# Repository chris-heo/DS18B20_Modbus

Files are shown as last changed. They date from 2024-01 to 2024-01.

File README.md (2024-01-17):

# Modbus adapter for DS18B20 temperature sensors (and more)

Quick facts:
* 7 channels for DS18B20 (and compatible devices)
* 1 ADC channel
* 8 pulse counters
* I2C interface for AMS AS5600 magnetic encoder
* Modbus RTU
* ATtiny1616

[Documentation](https://hobbyelektronik.org/w/index.php/DS18B20-Modbus-Adapter) (German)

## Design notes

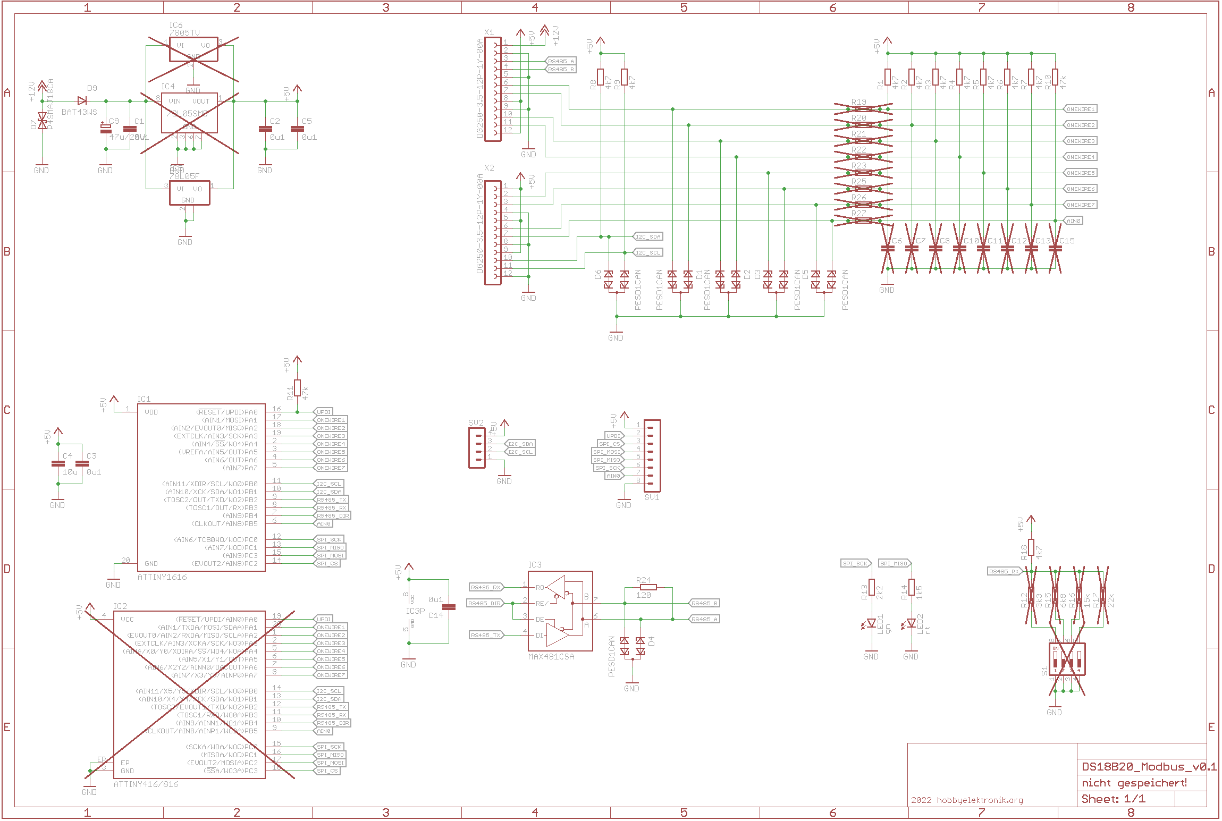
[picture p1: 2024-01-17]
hardware/DS18B20Modbus_v0.1_sch.png

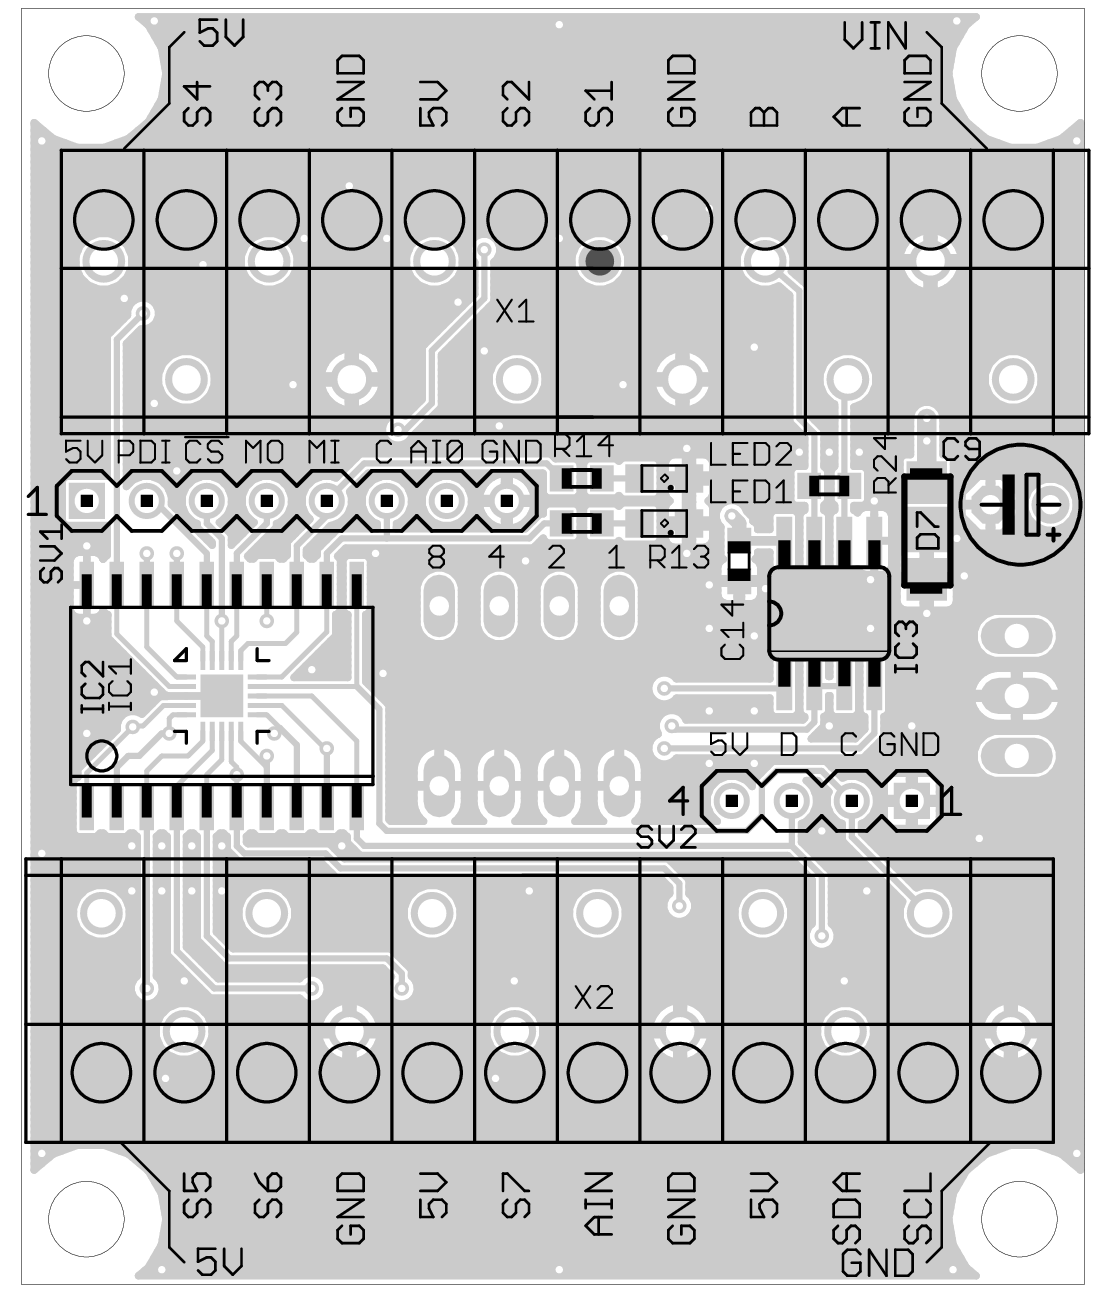
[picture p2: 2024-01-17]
hardware/DS18B20Modbus_v0.1_pcb_top_assy.png

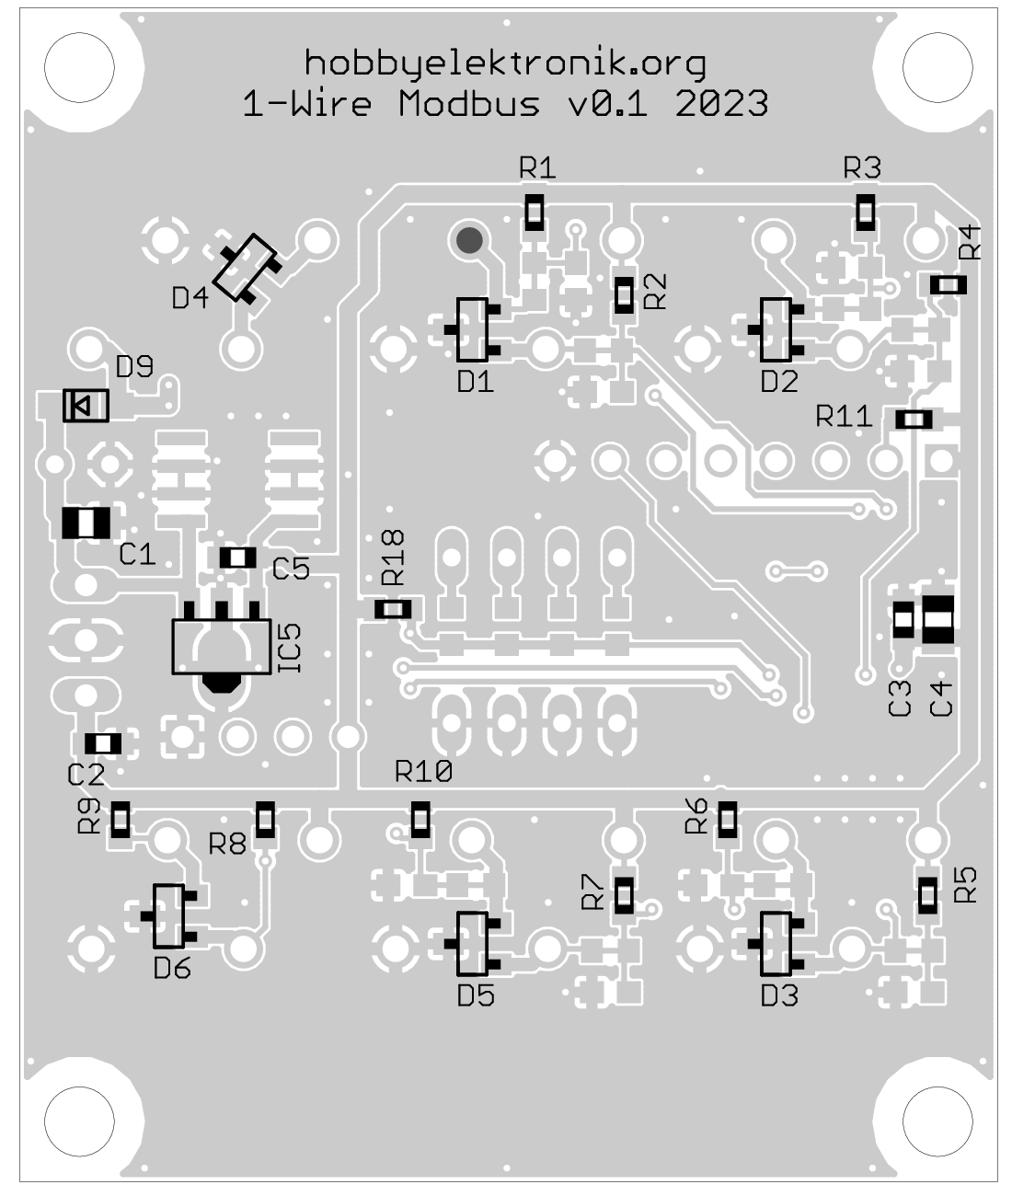
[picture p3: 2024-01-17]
hardware/DS18B20Modbus_v0.1_pcb_bot_assy.png

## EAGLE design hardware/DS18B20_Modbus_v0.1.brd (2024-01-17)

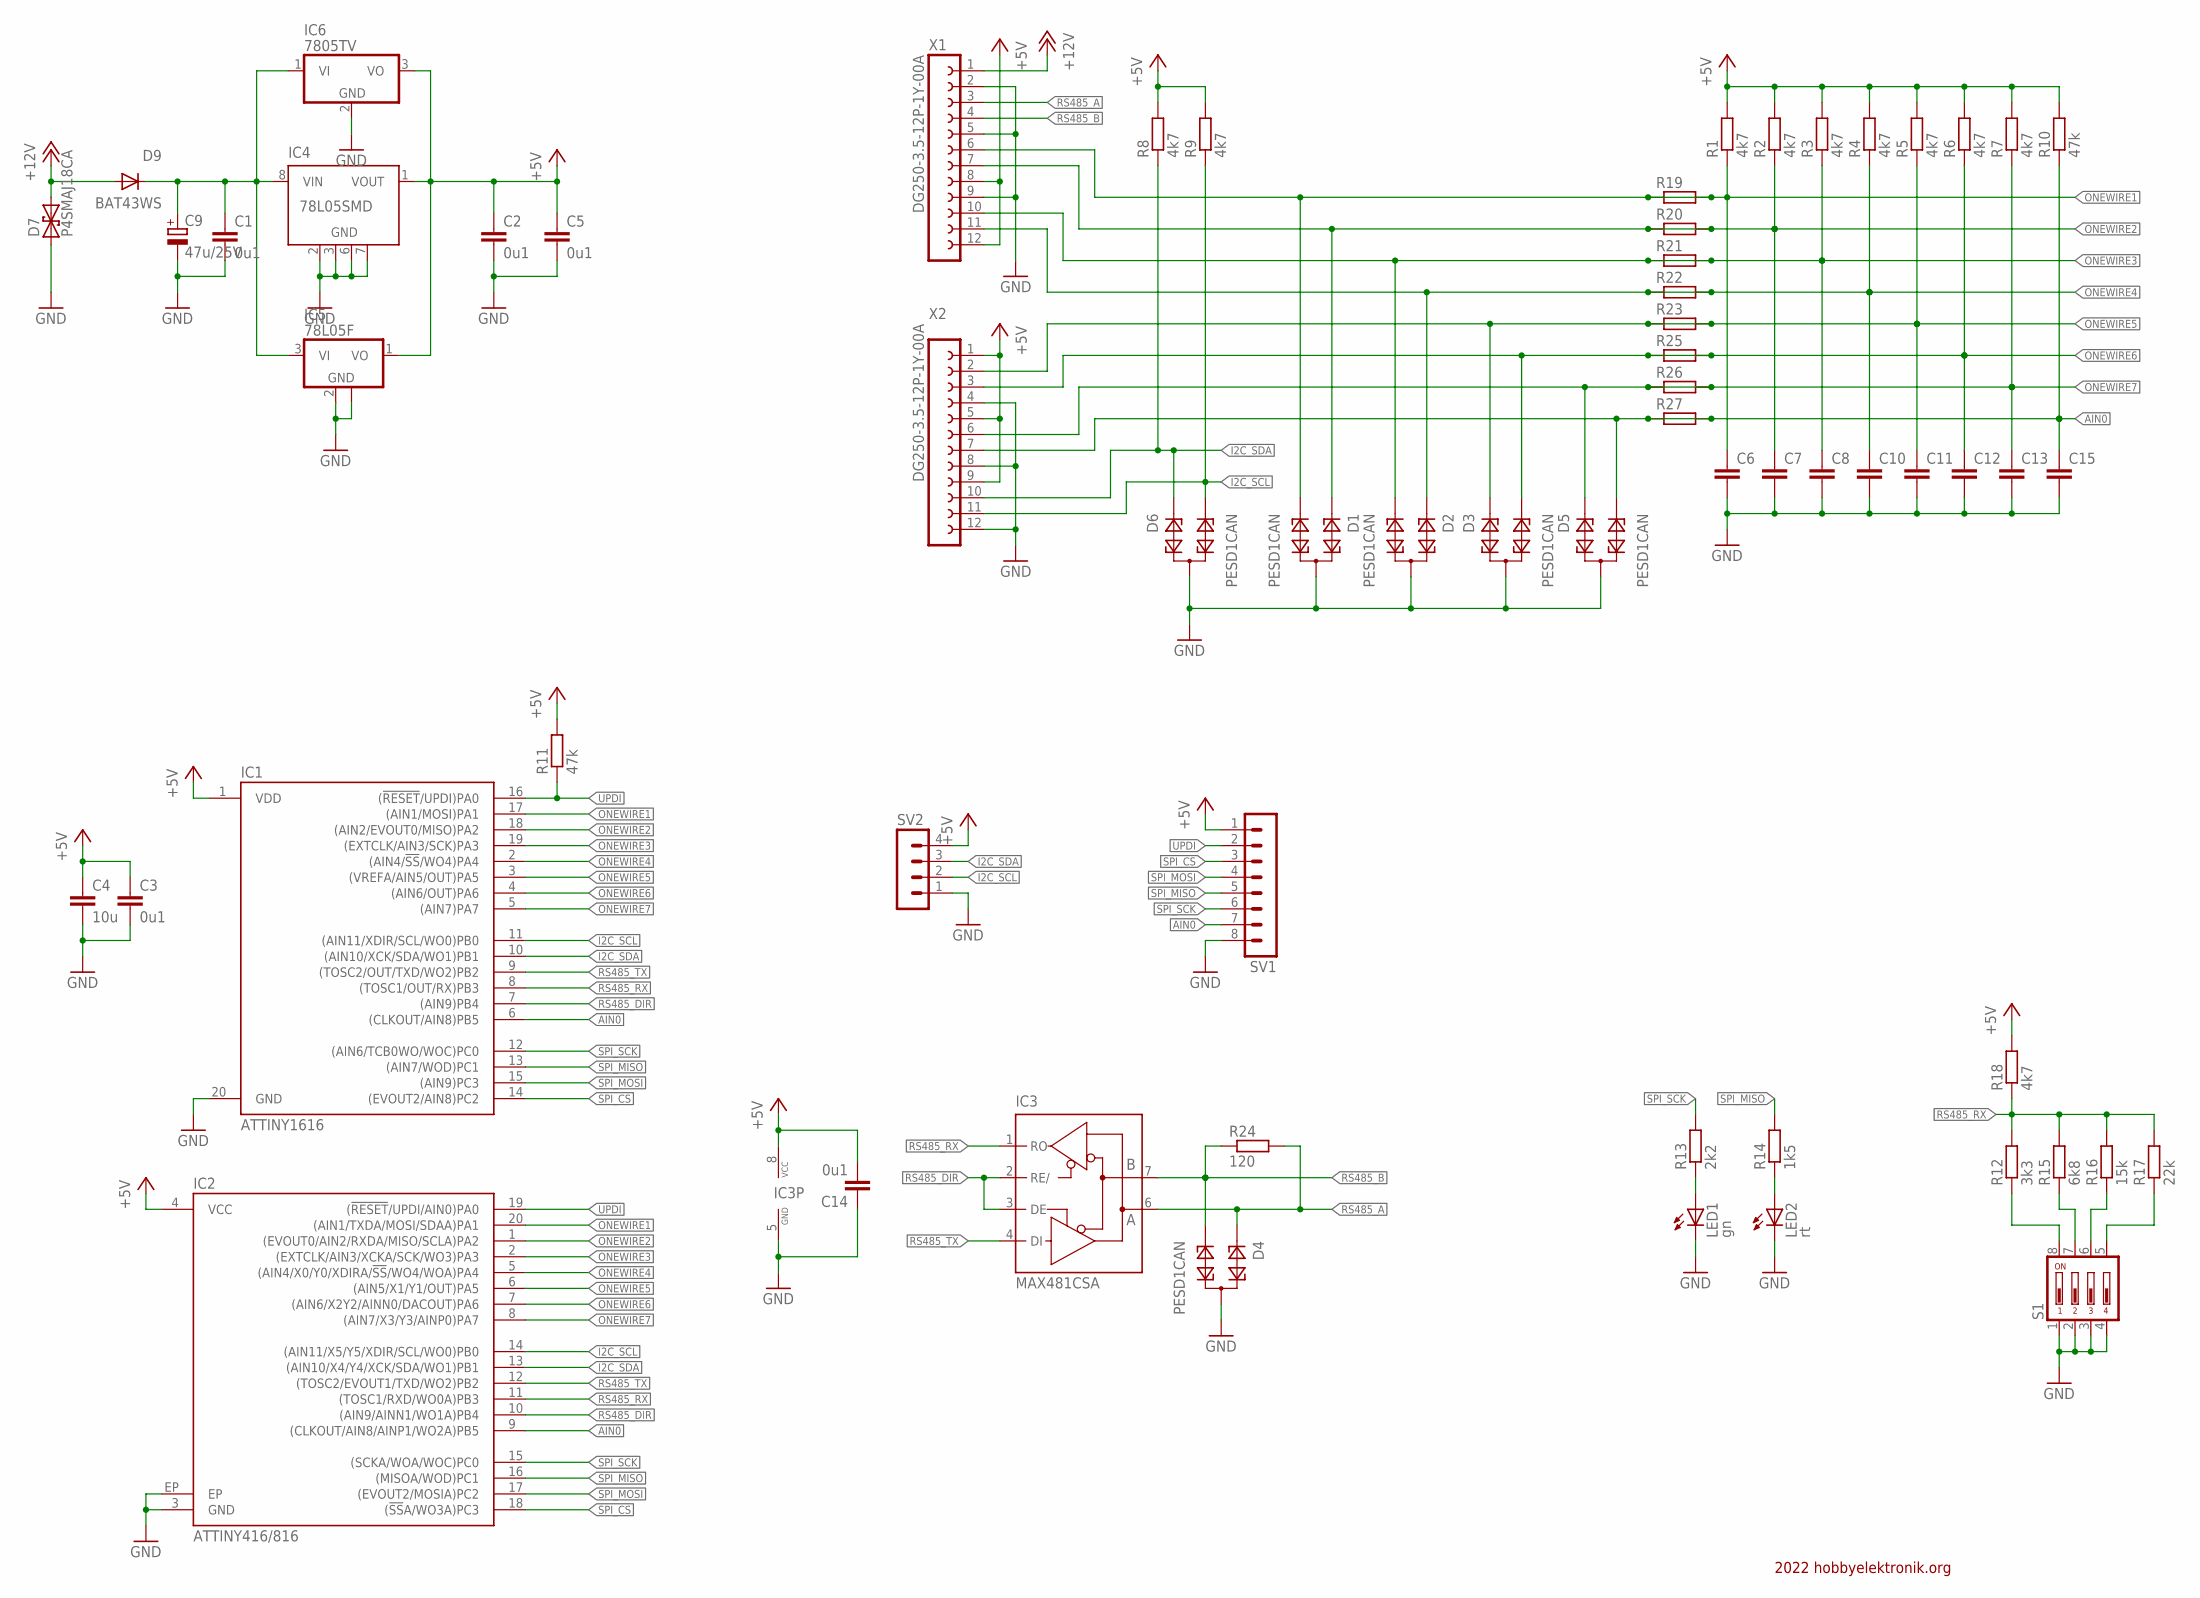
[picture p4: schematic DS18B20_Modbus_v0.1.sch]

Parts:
C1: 0u1; C0805
C2, C3, C5, C14: 0u1; C0603
C4: 10u; C0805
C6, C7, C8, C10, C11, C12, C13, C15: C-EUC0603; C0603
C9: 47u/25V; E2,5-5
D1, D2, D3, D4, D5, D6: PESD1CAN; SOT23
D7: P4SMAJ18CA; DO214AC
D9: BAT43WS; SOD323-W
IC1: ATTINY1616; SO20_T1616
IC2: ATTINY416/816; ZCL_VQFN-20
IC3: MAX481CSA; SO08
IC4: 78L05SMD; SO08
IC5: 78L05F; SOT89
IC6: 7805TV; TO220V
LED1: gn; SML0805
LED2: rt; SML0805
R1, R2, R3, R4, R5, R6, R7, R8, R9, R18: 4k7; R0603
R10, R11: 47k; R0603
R12: 3k3; R0603
R13: 2k2; R0603
R14: 1k5; R0603
R15: 6k8; R0603
R16: 15k; R0603
R17: 22k; R0603
R19, R20, R21, R22, R23, R25, R26, R27: R-EU_R0603; R0603
R24: 120; R0603
S1: DS04; DS-04
SV1: MA08-1R
SV2: MA04-1R
X1, X2: DG250-3.5-12P-1Y-00A

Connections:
+5V: C2.1, C3.1, C4.1, C5.1, C14.2, IC1.1 (VDD), IC2.4 (VCC), IC3.8 (VCC), IC4.1 (VOUT), IC5.1 (VO), IC6.3 (VO), R1.2, R2.2, R3.2, R4.2, R5.2, R6.2, R7.2, R8.2, R9.2, R10.2, R11.2, R18.2, SV1.1, SV2.4, X1.8, X1.12, X2.1, X2.5, X2.9
+12V: D7.2, D9.A, X1.1
AIN0: C15.1, D5.2, IC1.6 ((CLKOUT/AIN8)PB5), IC2.9 ((CLKOUT/AIN8/AINP1/WO2A)PB5), R10.1, R27.1, R27.2, SV1.7, X2.7
GND: C1.2, C2.2, C3.2, C4.2, C5.2, C6.2, C7.2, C8.2, C9.-, C10.2, C11.2, C12.2, C13.2, C14.1, C15.2, D1.3, D2.3, D3.3, D4.3, D5.3, D6.3, D7.1, IC1.20 (GND), IC2.3 (GND), IC2.EP, IC3.5 (GND), IC4.2 (GND), IC4.3 (GND), IC4.6 (GND), IC4.7 (GND), IC5.2 (GND), IC5.2@1 (GND), IC6.2 (GND), LED1.C, LED2.C, S1.1, S1.2, S1.3, S1.4, SV1.8, SV2.1, X1.2, X1.5, X1.9, X2.4, X2.8, X2.12
I2C_SCL: D6.2, IC1.11 ((AIN11/XDIR/SCL/WO0)PB0), IC2.14 ((AIN11/X5/Y5/XDIR/SCL/WO0)PB0), R9.1, SV2.2, X2.11
I2C_SDA: D6.1, IC1.10 ((AIN10/XCK/SDA/WO1)PB1), IC2.13 ((AIN10/X4/Y4/XCK/SDA/WO1)PB1), R8.1, SV2.3, X2.10
unnamed: R12.1, S1.8
unnamed: R15.1, S1.7
unnamed: R16.1, S1.6
unnamed: R17.1, S1.5
unnamed: LED1.A, R13.1
unnamed: LED2.A, R14.1
unnamed: C1.1, C9.+, D9.C, IC4.8 (VIN), IC5.3 (VI), IC6.1 (VI)
ONEWIRE1: C6.1, D1.2, IC1.17 ((AIN1/MOSI)PA1), IC2.20 ((AIN1/TXDA/MOSI/SDAA)PA1), R1.1, R19.1, R19.2, X1.6
ONEWIRE2: C7.1, D1.1, IC1.18 ((AIN2/EVOUT0/MISO)PA2), IC2.1 ((EVOUT0/AIN2/RXDA/MISO/SCLA)PA2), R2.1, R20.1, R20.2, X1.7
ONEWIRE3: C8.1, D2.2, IC1.19 ((EXTCLK/AIN3/SCK)PA3), IC2.2 ((EXTCLK/AIN3/XCKA/SCK/WO3)PA3), R3.1, R21.1, R21.2, X1.10
ONEWIRE4: C10.1, D2.1, IC1.2 ((AIN4/!SS!/WO4)PA4), IC2.5 ((AIN4/X0/Y0/XDIRA/!SS!/WO4/WOA)PA4), R4.1, R22.1, R22.2, X1.11
ONEWIRE5: C11.1, D3.1, IC1.3 ((VREFA/AIN5/OUT)PA5), IC2.6 ((AIN5/X1/Y1/OUT)PA5), R5.1, R23.1, R23.2, X2.2
ONEWIRE6: C12.1, D3.2, IC1.4 ((AIN6/OUT)PA6), IC2.7 ((AIN6/X2Y2/AINN0/DACOUT)PA6), R6.1, R25.1, R25.2, X2.3
ONEWIRE7: C13.1, D5.1, IC1.5 ((AIN7)PA7), IC2.8 ((AIN7/X3/Y3/AINP0)PA7), R7.1, R26.1, R26.2, X2.6
RS485_A: D4.1, IC3.6 (A), R24.2, X1.3
RS485_B: D4.2, IC3.7 (B), R24.1, X1.4
RS485_DIR: IC1.7 ((AIN9)PB4), IC2.10 ((AIN9/AINN1/WO1A)PB4), IC3.2 (RE/), IC3.3 (DE)
RS485_RX: IC1.8 ((TOSC1/OUT/RX)PB3), IC2.11 ((TOSC1/RXD/WO0A)PB3), IC3.1 (RO), R12.2, R15.2, R16.2, R17.2, R18.1
RS485_TX: IC1.9 ((TOSC2/OUT/TXD/WO2)PB2), IC2.12 ((TOSC2/EVOUT1/TXD/WO2)PB2), IC3.4 (DI)
SPI_CS: IC1.14 ((EVOUT2/AIN8)PC2), IC2.18 ((!SS!A/WO3A)PC3), SV1.3
SPI_MISO: IC1.13 ((AIN7/WOD)PC1), IC2.16 ((MISOA/WOD)PC1), R14.2, SV1.5
SPI_MOSI: IC1.15 ((AIN9)PC3), IC2.17 ((EVOUT2/MOSIA)PC2), SV1.4
SPI_SCK: IC1.12 ((AIN6/TCB0WO/WOC)PC0), IC2.15 ((SCKA/WOA/WOC)PC0), R13.2, SV1.6
UPDI: IC1.16 ((!RESET!/UPDI)PA0), IC2.19 ((!RESET!/UPDI/AIN0)PA0), R11.1, SV1.2

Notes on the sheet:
2022 hobbyelektronik.org

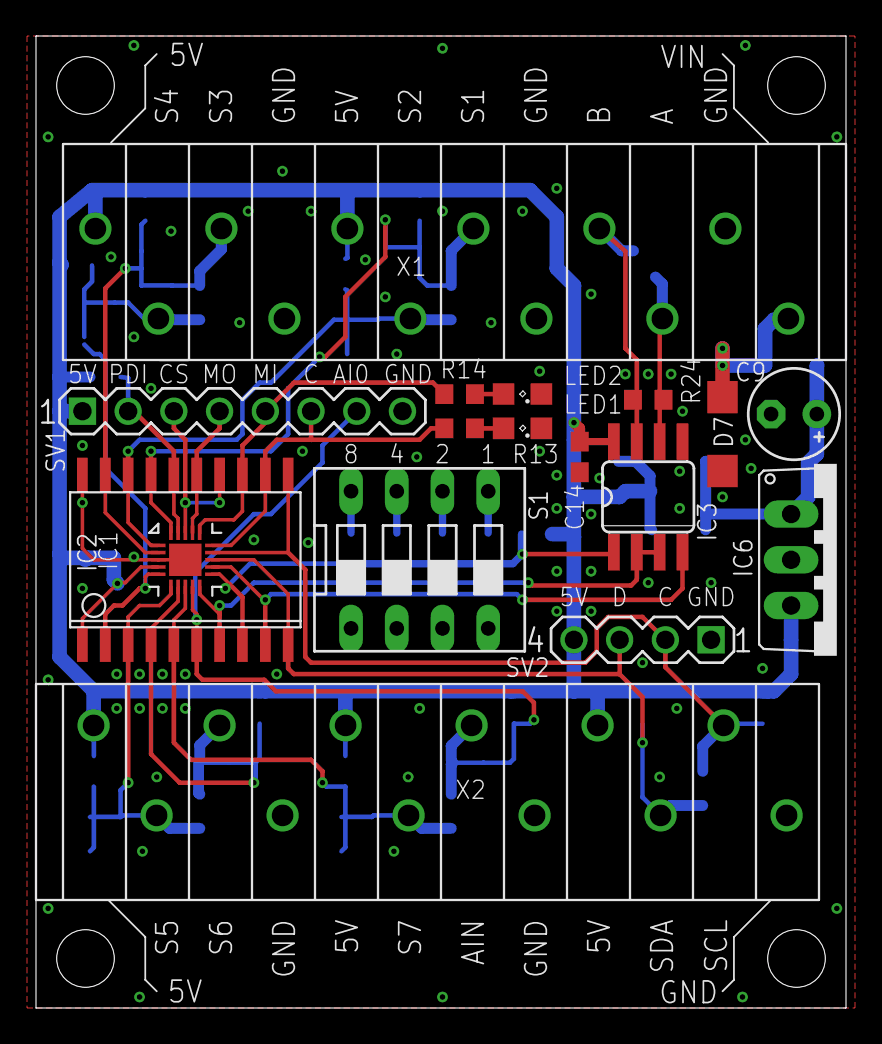
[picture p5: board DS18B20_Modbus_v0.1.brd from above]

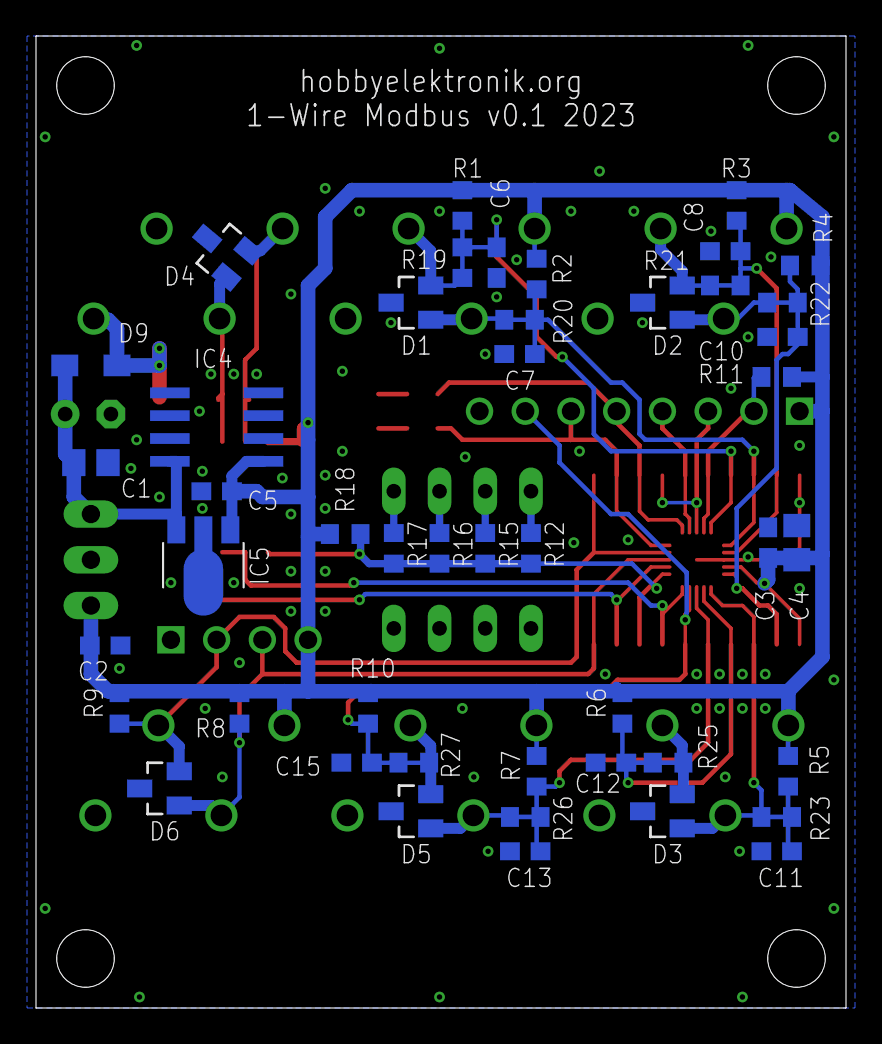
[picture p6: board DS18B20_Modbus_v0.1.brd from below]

Board: 2 copper layers, 45.0 x 54.0 mm, 63 parts (46 on the bottom side), 30 nets.

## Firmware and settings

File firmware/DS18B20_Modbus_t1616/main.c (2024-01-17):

#include <avr/io.h>
#include "onewire.h"
#include <avr/interrupt.h>
#include <util/delay.h>
#include <stdbool.h>
#include "yaMBSiavr.h"
#include "ds18b20.h"
#include "i2cm.h"
#include "as5600.h"
#include <avr/pgmspace.h>
#include "config.h"
#include <avr/wdt.h>

FUSE_t __fuse __attribute__((section (".fuse"))) =
{
    .WDTCFG = WINDOW_OFF_gc | PERIOD_16CLK_gc,
    .BODCFG = BOD_LVL_BODLEVEL2_gc | BOD_SAMPFREQ_1KHZ_gc | BOD_ACTIVE_ENABLED_gc | BOD_SLEEP_DIS_gc,
    .OSCCFG = (0 << FUSE_OSCLOCK_bp) | FREQSEL_16MHZ_gc,
    .TCD0CFG = (0 << FUSE_CMPDEN_bp) | (0 << FUSE_CMPCEN_bp) | (0 << FUSE_CMPBEN_bp) | (0 << FUSE_CMPAEN_bp) | (0 << FUSE_CMPD_bp) | (0 << FUSE_CMPC_bp) | (0 << FUSE_CMPB_bp) | (0 << FUSE_CMPA_bp),
    .SYSCFG0 = CRCSRC_NOCRC_gc | RSTPINCFG_UPDI_gc | (1 << FUSE_EESAVE_bp),
    .SYSCFG1 = CLKCTRL_CSUT_64K_gc,
    .APPEND = 0x00,
    .BOOTEND = 0x00,
};

volatile uint8_t sys_ticks = 0;

#define led_red_on() PORTC.OUTSET = PIN1_bm
#define led_red_off() PORTC.OUTCLR = PIN1_bm

#define led_green_on() PORTC.OUTSET = PIN0_bm
#define led_green_off() PORTC.OUTCLR = PIN0_bm

uint8_t modbus_act_cnt = 0;

const __flash uint8_t adc_scanchannels[] =
{
    ADC_SCANCHANNELS
};

//////////////////////////////////////////////////////////////////////////
// helper functions

#define array_length(arr) (sizeof(arr) / sizeof(typeof(*arr)))

inline bool postscaler8(uint8_t ticks_passed, uint8_t* postscaler, uint8_t scaling)
{
    *postscaler += ticks_passed;
    if(*postscaler >= scaling)
    {
        *postscaler -= scaling;
        return true;
    }
    return false;
}

inline bool postscaler16(uint8_t ticks_passed, uint16_t* postscaler, uint16_t scaling)
{
    *postscaler += ticks_passed;
    if(*postscaler >= scaling)
    {
        *postscaler -= scaling;
        return true;
    }
    return false;
}

//////////////////////////////////////////////////////////////////////////
// system ticks

void systick_init(void)
{
    TCB0.CTRLA = TCB_CLKSEL_CLKDIV1_gc | (1 << TCB_ENABLE_bp);
    //TCB0.CTRLB = TCB_CNTMODE_0_bm;
    TCB0.INTCTRL = 1 << TCB_CAPT_bp;
    TCB0.CCMP = 1600; // 100µs @ 16 MHz
}

ISR(TCB0_INT_vect)
{
    TCB0.INTFLAGS = 1 << TCB_CAPT_bp;
    modbusTickTimer();
    sys_ticks++;
}

//////////////////////////////////////////////////////////////////////////
// modbus stuff

volatile uint8_t instate = 0;
volatile uint8_t outstate = 0;
volatile uint16_t inputRegisters[MODBUS_REGS_INPUT_CNT];
volatile uint16_t holdingRegisters[MODBUS_REGS_HOLDING_CNT];

void modbusGet(void)
{

    if (modbusGetBusState() & (1<<ReceiveCompleted))
    {
        modbus_act_cnt = MODBUS_ACT_DURATION;
        led_green_off();
        
        switch(rxbuffer[1]) 
        {
            case fcReadCoilStatus: //read single/multiple coils
            {
                modbusExchangeBits(&outstate, 0, 8);
            }
            break;
            
            case fcReadInputStatus: //read single/multiple inputs
            {
                volatile uint8_t inps = 0; //ReadIns();
                modbusExchangeBits(&inps, 0, 8);
            }
            break;
            
            case fcReadHoldingRegisters: //read analog output registers
            {
                modbusExchangeRegisters(holdingRegisters, 0, MODBUS_REGS_HOLDING_CNT);
            }
            break;
            
            case fcReadInputRegisters: //read analog input registers (2 Bytes per register)
            {
                modbusExchangeRegisters(inputRegisters, 0, MODBUS_REGS_INPUT_CNT);
            }
            break;
            
            case fcForceSingleCoil: //write single bit
            {
                modbusExchangeBits(&outstate, 0, 8);
            }
            break;
            
            case fcPresetSingleRegister: //write analog output register (2 Bytes)
            {
                modbusExchangeRegisters(holdingRegisters, 0, MODBUS_REGS_HOLDING_CNT);
            }
            break;
            
            case fcForceMultipleCoils: //write multiple bits
            {
                modbusExchangeBits(&outstate, 0, 8);
            }
            break;
            
            case fcPresetMultipleRegisters: //write multiple analog output registers (2 Bytes each)
            {
                modbusExchangeRegisters(holdingRegisters, 0, 4);
            }
            break;

            case fcEncapsulatedInterfaceTransport:
            {
                modbusHandleDeviceId();
            }
            break;
            
            default: {
                modbusSendException(ecIllegalFunction);
            }
            break;
        }
    }
}

//////////////////////////////////////////////////////////////////////////
// temperatur sensor stuff

typedef enum
{
    tempsensors_idle = 0,
    tempsensors_start = 1,
    tempsensors_ongoing = 2,
    tempsensors_done = 3,
}   tempsensors_e;


inline void tempsensors_invalidate()
{
    for(uint8_t i = 0; i < 7; i++)
    {
        inputRegisters[i] = 0x8000;
    }
}

void tempsensors_tick()
{
    if(((holdingRegisters[0] >> 0) & 0x03) == tempsensors_start)
    {
        // invalidate input registers
        tempsensors_invalidate();

        // wait until modbus transfer is complete, then start conversion
        if((modbusGetBusState() & (1<<Transmitting)) == 0 && ds18b20_start() == true)
        {
            holdingRegisters[0] = (holdingRegisters[0] & ~(0x03)) | ((uint8_t)tempsensors_ongoing << 0);
            led_red_on(); // turn status LED on
        }
    }

    if(ds18b20_tick() == true)
    {
        for(uint8_t i = 0; i < 7; i++)
        {
            int16_t temp = ds18b20_get_temp_fixed(i+1);
            inputRegisters[MODBUS_REGOFFS_TEMP + i] = temp;
        }
        inputRegisters[MODBUS_REGOFFS_TEMP + 7]++; // increase read count
        
        holdingRegisters[0] = (holdingRegisters[0] & ~(0x03)) | ((uint8_t)tempsensors_done << 0);
        led_red_off();
    }
}

//////////////////////////////////////////////////////////////////////////
// rotary encoder stuff

uint8_t rotenc_errors = 1;

void rotenc_tick()
{

    if(rotenc_errors > 5)
    {
        // if there are multiple errors, re-initialize I2C
        i2cm_disable();
        i2cm_init();
    }

    if(rotenc_errors > 0)
    {
        // if there was an error, re-initialize the rotary encoder
        if(as5600_config(
            ROTENC_POWERMODE, ROTENC_HYSTERESIS, 
            as5600_outputstage_analog, as5600_pwmfreq_115Hz, 
            ROTENC_SLOWFILTER, ROTENC_FASTFILTER, ROTENC_WATCHDOG) == false)
        {
            goto rotenc_error;
        }
    }

    uint8_t data[3];
    if(i2cm_readregs(AS5600_ADDR, as5600_register_status, data, sizeof(data)) != i2c_status_ok)
    {
        goto rotenc_error;
    }

    uint8_t status = (data[0] >> 3) & 0x07;
    inputRegisters[MODBUS_REGOFFS_ROTENC_ANGLE] = (data[1] << 8) | data[2]; // angle_raw

    if(i2cm_readregs(AS5600_ADDR, as5600_register_agc, data, sizeof(data)) != i2c_status_ok)
    {
        goto rotenc_error;
    }

    inputRegisters[MODBUS_REGOFFS_ROTENC_STATUS] = (status << 8) | data[0]; // status & gain
    inputRegisters[MODBUS_REGOFFS_ROTENC_MAGNITUDE] = (data[1] << 8) | data[2]; // magnitude

    rotenc_errors = 0;

    return;

rotenc_error:
    rotenc_errors++;

    inputRegisters[MODBUS_REGOFFS_ROTENC_STATUS] = 0x08 << 8;
    inputRegisters[MODBUS_REGOFFS_ROTENC_ANGLE] = 0;
    inputRegisters[MODBUS_REGOFFS_ROTENC_MAGNITUDE] = 0;
}

//////////////////////////////////////////////////////////////////////////
// adc stuff

uint16_t adc_values[array_length(adc_scanchannels)];
uint8_t adc_currchan = 0;

inline void adc_startconv()
{
    ADC0.COMMAND = ADC_STCONV_bm;
}

void adc0_init()
{
#if (ADC0_REF == VREF_INT_0V55)
    VREF.CTRLA = VREF_ADC0REFSEL_0V55_gc;
#elif (ADC0_REF == VREF_INT_1V1)
    VREF.CTRLA = VREF_ADC0REFSEL_1V1_gc;
#elif ADC0_REF == VREF_INT_1V5
    VREF.CTRLA = VREF_ADC0REFSEL_1V5_gc;
#elif ADC0_REF == VREF_INT_2V5
    VREF.CTRLA = VREF_ADC0REFSEL_2V5_gc;
#elif ADC0_REF == VREF_INT_4V34
    VREF.CTRLA = VREF_ADC0REFSEL_4V34_gc;
#endif

    VREF.CTRLB = 
#if ADC0_REF != VREF_VDD
    (1<<VREF_ADC0REFEN_bp) | 
#endif
    (0<<VREF_DAC0REFEN_bp);

    ADC0.CTRLB = ADC0_ACCUMULATE;
    //ADC0.CTRLC = (1<<ADC_SAMPCAP_bp) | ADC_REFSEL_INTREF_gc | ADC_PRESC_DIV64_gc;
    ADC0.CTRLC = (1<<ADC_SAMPCAP_bp) | 
#if ADC0_REF == VREF_VDD
    ADC_REFSEL_VDDREF_gc
    //#pragma message ( "VDD used as reference" )
#else
    //#pragma message ( "Internal Ref used as reference" )
    ADC_REFSEL_INTREF_gc
#endif
     | ADC_PRESC_DIV64_gc;
    ADC0.CTRLD =  ADC_INITDLY_DLY16_gc | ADC_ASDV_ASVON_gc | 0;
    ADC0.SAMPCTRL = 0;
    ADC0.CTRLE = ADC_WINCM_NONE_gc;

    ADC0.CTRLA = (1<<ADC_ENABLE_bp) | (0<<ADC_FREERUN_bp) | ADC_RESSEL_10BIT_gc | (0<<ADC_RUNSTBY_bp);

    adc_currchan = 0;
    ADC0.MUXPOS = adc_scanchannels[adc_currchan];
    adc_startconv();
}

uint8_t adc0_tick()
{
    if(ADC0.INTFLAGS & (1<<ADC_RESRDY_bp))
    {
        uint8_t updated_channel = adc_currchan;
        adc_values[adc_currchan] = ADC0.RES;
        ADC0.INTFLAGS |= (1<<ADC_RESRDY_bp);

        adc_currchan++;
        if(adc_currchan >= array_length(adc_scanchannels))
        adc_currchan = 0;

        ADC0.MUXPOS = adc_scanchannels[adc_currchan];
        adc_startconv();

        return updated_channel;
    }
    return 0xFF; // no update
}

void adc_tick()
{
    uint8_t adc_updch = adc0_tick();
    if(adc_updch != 0xFF)
    {
        inputRegisters[MODBUS_REGOFFS_ADC] = adc_values[adc_updch];
        if(PORTB.IN & PIN5_bm)
        {
            inputRegisters[MODBUS_REGOFFS_ADC] |= 0x80;
        }
    }
}

//////////////////////////////////////////////////////////////////////////
/// Pulse counter

typedef struct
{
    uint8_t h_len;
    uint8_t l_len;
    uint16_t h_cnt;
    uint16_t l_cnt;
    bool h_cnt_rollover;
    bool l_cnt_rollover;
}   pulsecounter_ch_t;

#define PULSECOUNTER_CH_COUNT 9

pulsecounter_ch_t pulsecounter_ch[PULSECOUNTER_CH_COUNT];

void pulsecounter_init(void)
{
    for(uint8_t i = 0; i < PULSECOUNTER_CH_COUNT; i++)
    {
        pulsecounter_ch_t *ch = &pulsecounter_ch[i];
        ch->h_len = 0xFF;
        ch->l_len = 0xFF;
        ch->h_cnt = 0;
        ch->l_cnt = 0;
        ch->h_cnt_rollover = false;
        ch->l_cnt_rollover = false;
    }
}

bool pulsecounter_check_ch(uint8_t val, pulsecounter_ch_t *ch)
{
    bool updated = false;
    if(val > 0)
    {
        ch->l_len = 0;
        if(ch->h_len < 0xFF)
        {
            ch->h_len++;

            if(ch->h_len == PULSECOUNTER_H_THRESHOLD)
            {
                ch->h_cnt++;
                updated = true;
                if(ch->h_cnt == 0)
                {
                    ch->h_cnt_rollover = true;
                }
            }
        }
    }
    else
    {
        ch->h_len = 0;
        if(ch->l_len < 0xFF)
        {
            ch->l_len++;

            if(ch->l_len == PULSECOUNTER_L_THRESHOLD)
            {
                updated = true;
                ch->l_cnt++;
                if(ch->l_cnt == 0)
                {
                    ch->l_cnt_rollover = true;
                }
            }
        }
    }
    return updated;
}

void pulsecounter_tick(void)
{
    uint8_t val = PORTA.IN;
    for(uint8_t i = 0; i < 8; i++)
    {
        if(pulsecounter_check_ch(val & 1, &pulsecounter_ch[i]) == true)
        {
            inputRegisters[MODBUS_REGOFFS_PULSECOUNTER + i] = pulsecounter_ch[i].l_cnt;
        }
        val >>= 1;
    }

    val = PORTB.IN & (1<<5);
    uint8_t i = 8;
    pulsecounter_check_ch(val, &pulsecounter_ch[i]);
    inputRegisters[MODBUS_REGOFFS_PULSECOUNTER + i] = pulsecounter_ch[i].l_cnt;
}

int main(void)
{
    CCP = CCP_IOREG_gc;
    CLKCTRL.MCLKCTRLB = /*CLKCTRL_PDIV_4X_gc |*/ (0 << CLKCTRL_PEN_bp);

    PORTA.DIRSET = DS18B20_MAP;

    PORTB.DIRSET = (1<<PIN4_bp) | (1<<PIN2_bp); // UART TX
    PORTB.DIRCLR = (1<<PIN3_bp); // UART RX
    PORTB.PIN3CTRL = (1<<PORT_PULLUPEN_bp); // enable pull-up for UART RX

    PORTC.DIRSET = (1<<PIN1_bp) | (1<<PIN0_bp); // status LEDs

    systick_init();
    uint8_t sys_ticks_last = sys_ticks;

    i2cm_init();
    modbusSetAddress(MODBUS_ADDRESS);
    modbusInit();
    adc0_init();
    tempsensors_invalidate();
    pulsecounter_init();

    //uart_init();
    sei();

    // everything initialized - turn on the status LED
    // it will flicker on modbus activity
    led_green_on();

    uint16_t postscale_i2c = 0;
    uint8_t postscale_pulsecounter = 0;

    while(1)
    {
        uint8_t tmp = sys_ticks;
        uint8_t ticks_passed = tmp - sys_ticks_last;
        sys_ticks_last = tmp;

        modbusGet();

        if(ticks_passed > 0)
        {
            tempsensors_tick();
            adc_tick();
            
            if(postscaler16(ticks_passed, &postscale_i2c, ROTENC_UPDATE_INTERVAL))
            {
                rotenc_tick();
            }

            if(postscaler8(ticks_passed, &postscale_pulsecounter, PULSECOUNTER_TICK_INTERVAL))
            {
                pulsecounter_tick();
            }

            if(modbus_act_cnt > 0)
            {
                if(ticks_passed > modbus_act_cnt)
                {
                    modbus_act_cnt = 0;
                }
                else
                {
                    modbus_act_cnt -= ticks_passed;
                }

                if(modbus_act_cnt == 0)
                    led_green_on();
            }

            wdt_reset();
        }
    }
}

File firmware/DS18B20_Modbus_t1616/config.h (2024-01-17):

#ifndef CONFIG_H_
#define CONFIG_H_
#include "as5600.h"
#include "config_helper.h"

//////////////////////////////////////////////////////////////////////////
// Input usage

// currently, only DS18B20 can be set, 
// pulse counter (negative pulses) is active for all channels
// ADC is only active for AIN

#define S1_USAGE USAGE_DS18B20
#define S2_USAGE USAGE_DS18B20
#define S3_USAGE USAGE_DS18B20
#define S4_USAGE USAGE_DS18B20
#define S5_USAGE USAGE_DS18B20
#define S6_USAGE USAGE_DS18B20
#define S7_USAGE USAGE_DS18B20

//////////////////////////////////////////////////////////////////////////
// Modbus

#define MODBUS_BAUDRATE 19200L

#ifndef MODBUS_ADDRESS
#define MODBUS_ADDRESS 10
#endif

// activity LED blink duration in 100 us steps (up to 255)
#define MODBUS_ACT_DURATION 200

// this is a bit of a cludge, register counts should be determined automagically
#define MODBUS_REGS_INPUT_CNT 21
#define MODBUS_REGS_HOLDING_CNT 1

//////////////////////////////////////////////////////////////////////////
// Temperature sensor settings

// Modbus register offsets, 8 input registers are occupied (7 sensors + acquisition counter)
#define MODBUS_REGOFFS_TEMP 0

//////////////////////////////////////////////////////////////////////////
// ADC settings

//#define ADC0_REF VREF_INT_0V55
//#define ADC0_REF VREF_INT_1V1
//#define ADC0_REF VREF_INT_1V5
//#define ADC0_REF VREF_INT_2V5
//#define ADC0_REF VREF_INT_4V34
#define ADC0_REF VREF_VDD

// accumulation for ADC inputs, please note that the values actually get accumulated (no averaging)
#define ADC0_ACCUMULATE ADC_SAMPNUM_ACC8_gc

#define ADC_SCANCHANNELS ADC_MUXPOS_AIN8_gc,

// modbus register offset (depending on adc_scanchannels)
#define MODBUS_REGOFFS_ADC 11

//////////////////////////////////////////////////////////////////////////
// Rotary Encoder settings

// rotary encoder update interval in 100 us steps (up to 65535)
#define ROTENC_UPDATE_INTERVAL 1000

#define ROTENC_POWERMODE as5600_powermode_lpm1
#define ROTENC_HYSTERESIS as5600_hysteresis_off
#define ROTENC_SLOWFILTER as5600_slowfilter_16x
#define ROTENC_FASTFILTER as5600_fastfilterthrs_off
#define ROTENC_WATCHDOG false

// modbus register offset
#define MODBUS_REGOFFS_ROTENC 8
#define MODBUS_REGOFFS_ROTENC_STATUS (MODBUS_REGOFFS_ROTENC+0)
#define MODBUS_REGOFFS_ROTENC_ANGLE  (MODBUS_REGOFFS_ROTENC+1)
#define MODBUS_REGOFFS_ROTENC_MAGNITUDE (MODBUS_REGOFFS_ROTENC+2)


//////////////////////////////////////////////////////////////////////////
// Pulse counter

// pulse counter tick interval in 100 us steps, the qualification periods are based on this (up to 255)
#define PULSECOUNTER_TICK_INTERVAL 5

// threshold of ticks after which the counter shall be incremented, must be less than 255
// PULSECOUNTER_H_THRESHOLD can currently be ignored, only low pulses are counted
#define PULSECOUNTER_H_THRESHOLD 20
#define PULSECOUNTER_L_THRESHOLD 20

// modbus register offset
#define MODBUS_REGOFFS_PULSECOUNTER 12

#endif /* CONFIG_H_ */
